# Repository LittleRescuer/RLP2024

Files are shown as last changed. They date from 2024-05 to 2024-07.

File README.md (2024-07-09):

# Little Rescuer
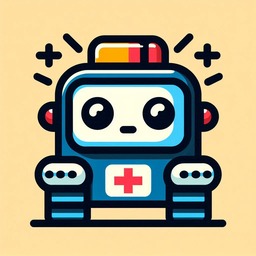
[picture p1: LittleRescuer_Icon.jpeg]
Project Icon


## Descripción

"Little Rescuer" es el prototipo de un robot autónomo diseñado para intervenir rápidamente en situaciones de emergencia en la carretera. Este dispositivo, con forma de automóvil compacto, está equipado con una variedad de funciones para garantizar la seguridad y el bienestar de los conductores y pasajeros involucrados en un accidente.

Cuando se produce un accidente, "Little Rescuer" se tiene que dejar en el suelo para que rápidamente se desplace y se posicione estratégicamente a 200 metros detrás del vehículo afectado.

Una vez en posición, "Little Rescuer" despliega una cámara que puede girar 180 grados, para capturar imágenes de la escena del accidente. Estas imágenes se envían de inmediato  a los contactos de emergencia designados por el conductor, proporcionando una rápida confirmación de que todos están bien. Una vez realizado el aviso, dicha cámara gira y se queda enfocando al tráfico para ir controlándolo.

Además de tomar fotografías, "Little Rescuer" activa su luz rotativa de emergencia V-16 para alertar a otros conductores sobre la presencia del accidente. Esta función ayuda a prevenir colisiones adicionales y garantiza la seguridad en la carretera.

En resumen, "Little Rescuer" es un valioso aliado en situaciones de emergencia en la carretera, ofreciendo una respuesta rápida y coordinada para proteger la seguridad y el bienestar de todos los involucrados en un accidente de tráfico, evitando situaciones de peligro al tener a peatones en la calzada.

## Imágenes
A continuación, mostramos una imagen de como se ve físicamente el robot. No obstante, hay más imágenes en la [siguiente carpeta](./img):
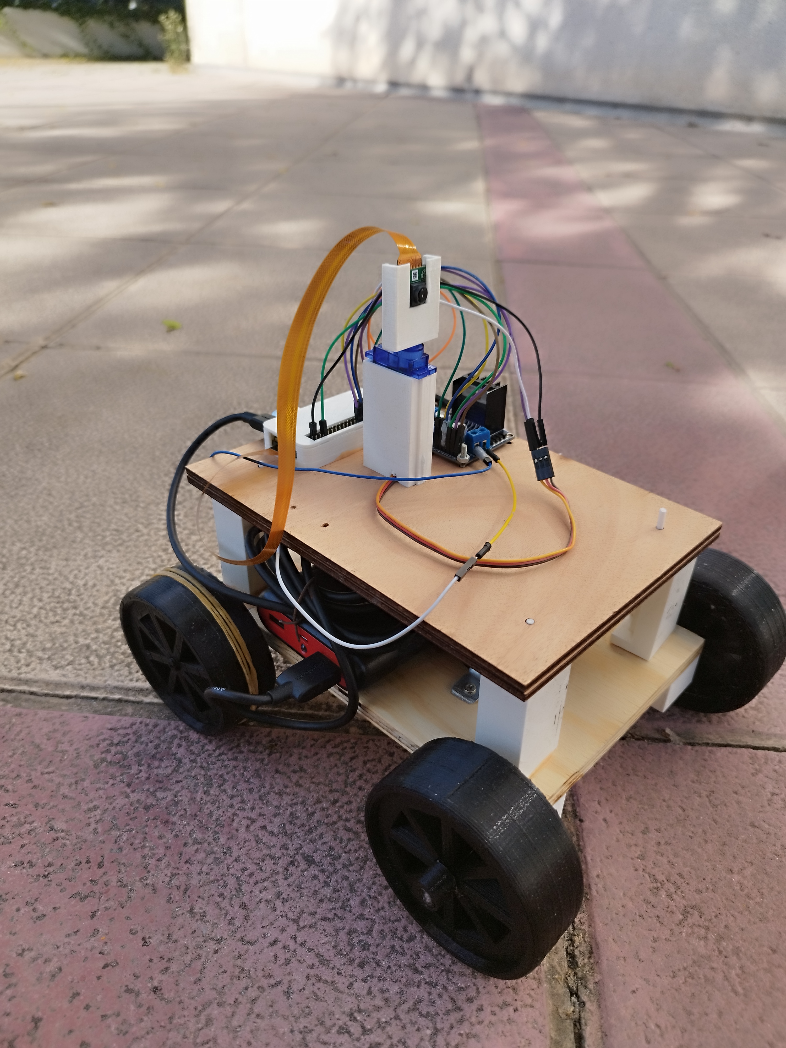
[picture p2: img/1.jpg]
Little Rescuer Image


## Librerías

- Python 3.x
- Raspberry Pi OS Lite
- OpenCV 4.8.0+
- gpiozero
- requests
- picamera2
- numpy
- RPi.GPIO

### Hardware

| Imagen | Descripción | Link |
| --- | --- | --- |
| Cámara Raspberry Pi v2 - 8 Megapixels | Cámara Raspberry Pi v2 - 8 Megapixels | [Link](https://tienda.bricogeek.com/accesorios-raspberry-pi/822-camara-raspberry-pi-v2-8-megapixels.html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) |
| Kit básico Raspberry Pi Zero Wifi + MicroSD 32GB | Kit básico Raspberry Pi Zero Wifi + MicroSD 32GB | [Link](https://tienda.bricogeek.com/placas-raspberry-pi/1082-kit-basico-raspberry-pi-zero-wifi-microsd-32gb.html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) |
| Controlador de motores TB6612FNG | Controlador de motores TB6612FNG | [Link](https://tienda.bricogeek.com/controladores-motores/999-controlador-de-motores-tb6612fng.html?gad_source=1) |
| Motor con eje ángulo recto y reductora 48:1 | Motor con eje ángulo recto y reductora 48:1| [Link](https://tienda.bricogeek.com/motores-dc/1048-motor-con-eje-angulo-recto-y-reductora-481.html) |
| Batería AA recargable - NiMH 2500mAh | Batería AA recargable - NiMH 2500mAh| [Link](https://tienda.bricogeek.com/baterias-lipo/315-bateria-aa-recargable-nimh-2500mah.html) |
| Base para baterías (4xAA) | Base para baterías (4xAA)| [Link](https://tienda.bricogeek.com/componentes/160-base-para-baterias-4xaa.html) |
| Luz emergencia V16 | Luz emergencia V16| [Link](https://www.amazon.es/dp/B0CPB1296V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) |
| Motor servo SG90 | Motor servo SG90| [Link](https://www.amazon.com/-/es/DIYables-grados-Arduino-ESP8266-Raspberry/dp/B0C7BL12RG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) |
| Antena GPS (SIM808) | Antena GPS (SIM808)| [Link](https://www.amazon.com/-/es/SIM808-SIM908-desarrollo-disponible-arduino/dp/B0CJ7VSG82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) |
| Power Bank 10000mAh Dual 2.4A Cargador de Banco de Energía de Alta Velocidad Entrada USB-C Paquete de Bater ía Externa para Teléfono Celular iPhone 12 iPad Samsung S21 Huawei Xiaomi etc | Power Bank 10000mAh Dual 2.4A Cargador de Banco de Energía de Alta Velocidad Entrada USB-C Paquete de Bater ía Externa para Teléfono Celular iPhone 12 iPad Samsung S21 Huawei Xiaomi etc| [Link](https://www.amazon.es/10000mAh-Cargador-Energ%C3%ADa-Velocidad-Tel%C3%A9fono/dp/B09K3BQBW6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) |
| Cable USB C a Micro USB | Cable USB C a Micro USB| [Link](https://www.amazon.com/-/es/flexible-soporta-sincronizaci%C3%B3n-compatible-MacBook/dp/B0BX5G8WNZ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) |

### Schematic
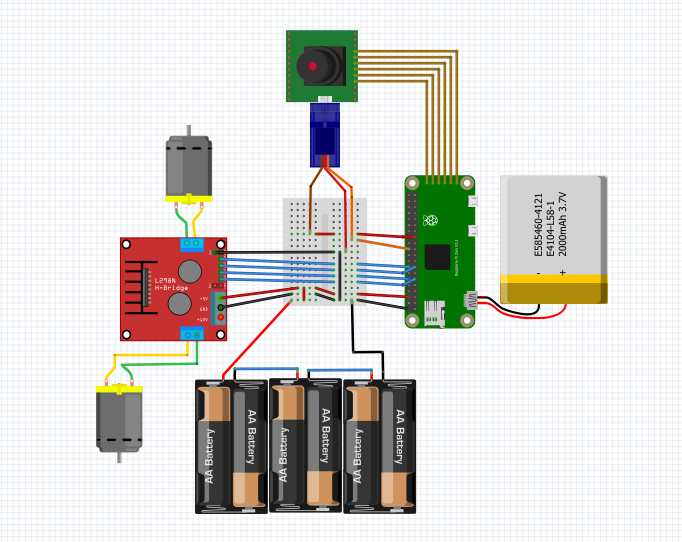
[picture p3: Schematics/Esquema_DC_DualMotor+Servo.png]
Schematic


### 3D

Se pueden encontrar los componentes 3D  [aquí](./Modelo/Componenetes%20Chasis)

### Diagrama de arquitectura del Software
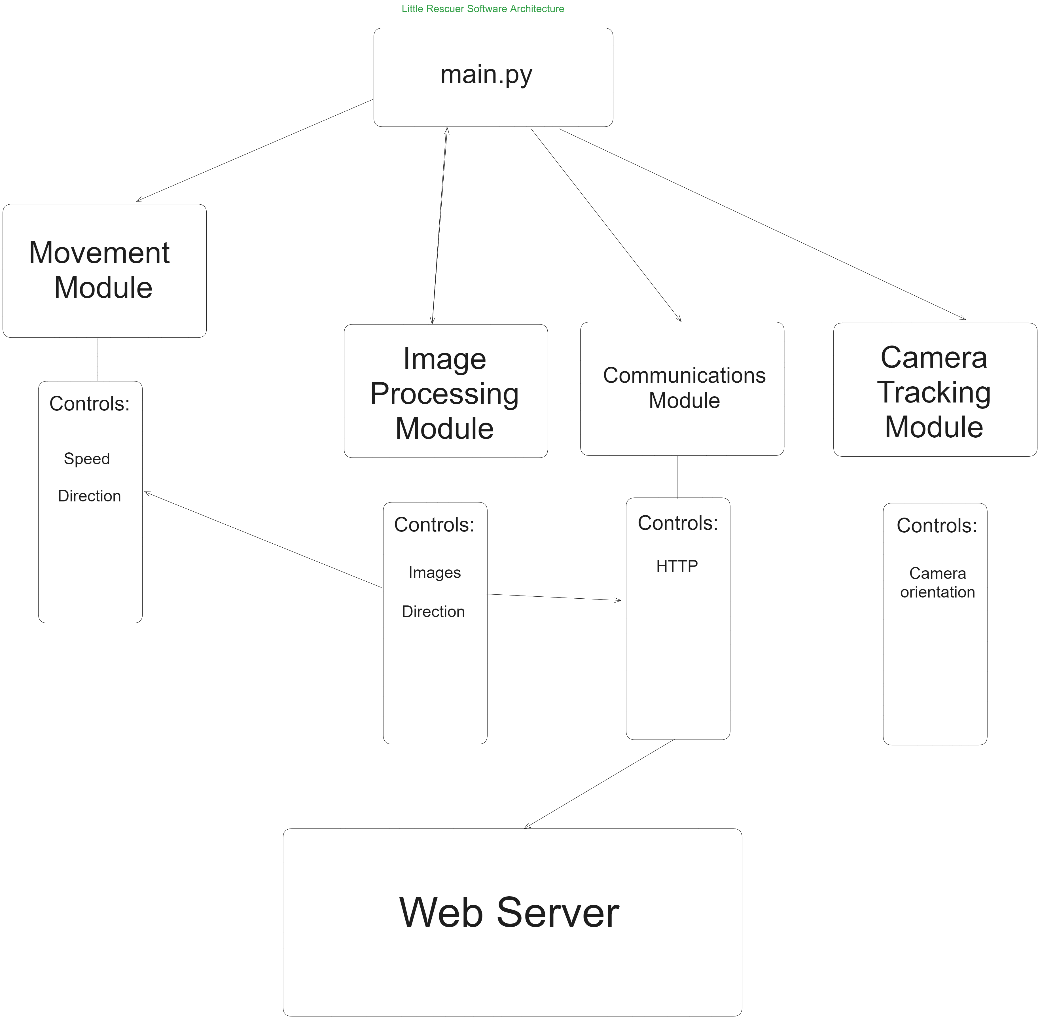
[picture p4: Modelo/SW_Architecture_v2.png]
Diagrama de arquitectura del Software del proyecto LittleRescuer (UAB)


### Página Web

Little Rescuer también cuenta con una página web donde se pueden ver forografías tomadas por el robot. Estas fotografías se realizan una vez el robot ha llegado a la distancia de seguridad de 200 metros alejado del vehículo averiado. Se muestran todas las imágenes que se han realizado con la fecha de realización y un botón de descarga. La página web se puede consultar [aquí](https://little-rescuer.vercel.app).

### Refs
Los proyectos que hemos usado como referencia son:
- [Autonomous Autonavigation Robot (Arduino)](https://www.instructables.com/Autonomous-Autonavigation-Robot-Arduino/)
- [Self Driving Car Using Arduino(autonomous Guided Vechicle)](https://www.instructables.com/Self-Driving-Car-Using-Arduinoautonomous-Guided-Ve/)
- [PythonRobotics](https://github.com/AtsushiSakai/PythonRobotics)
- [DeepPiCar](https://github.com/dctian/DeepPiCar)

### Autores
- Marc Giró Palacios
- Angel Antonio Gomez Nicolas
- Adrian Stoiciu
- Miguel Vallina Samaniego

### Agradecimientos

Queremos agradecer a nuestros 3 profesores de la asignatura:

- Fernando Luis Vilariño Freire
- Carlos García Calvo
- Vernon Stanley Albayeros Duarte

Gracias a su apoyo, este proyecto ha podido superar todos sus altibajos y llegar a buen término con éxito. Estamos agradecidos por el apoyo y la orientación brindada por nuestros profesores a lo largo de este proyecto. Durante los momentos críticos, ofrecieron su experiencia y conocimientos, permitiéndonos encontrar soluciones efectivas.

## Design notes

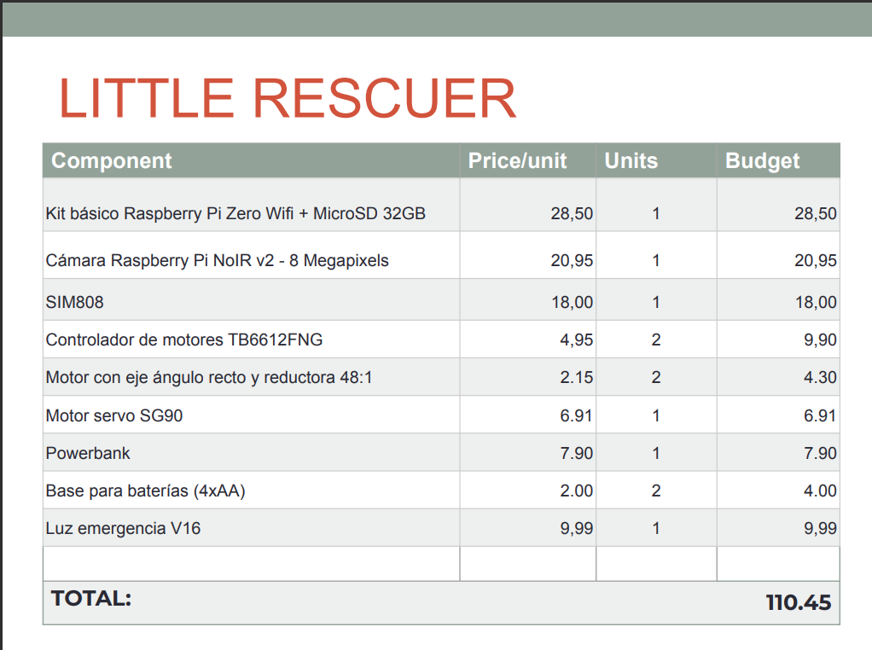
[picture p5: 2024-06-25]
Hardware/Screenshot 2024-06-25 114614.png

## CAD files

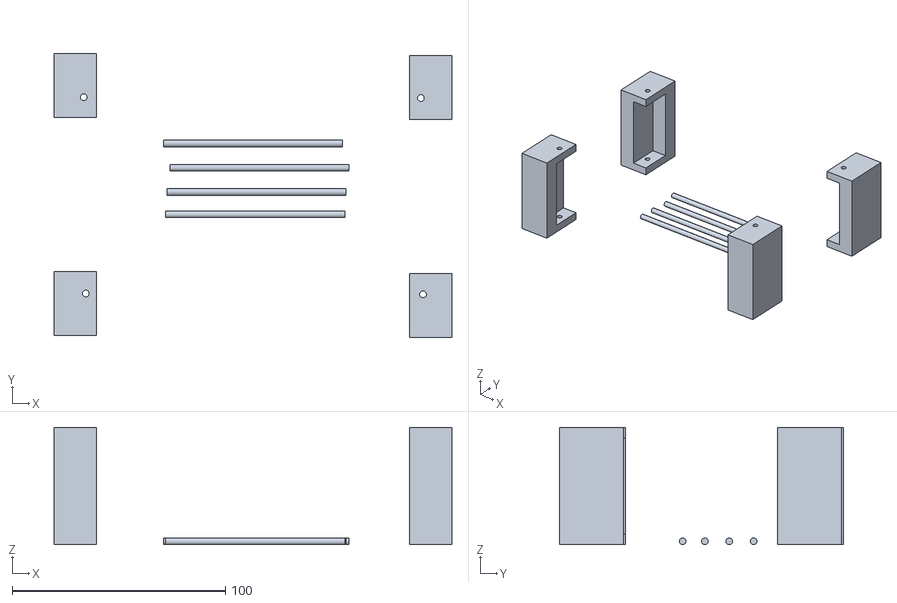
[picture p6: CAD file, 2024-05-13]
Modelo/Componenetes Chasis/LittleRescuer_Middle_Support.stl
186.5 x 133.0 x 55.0

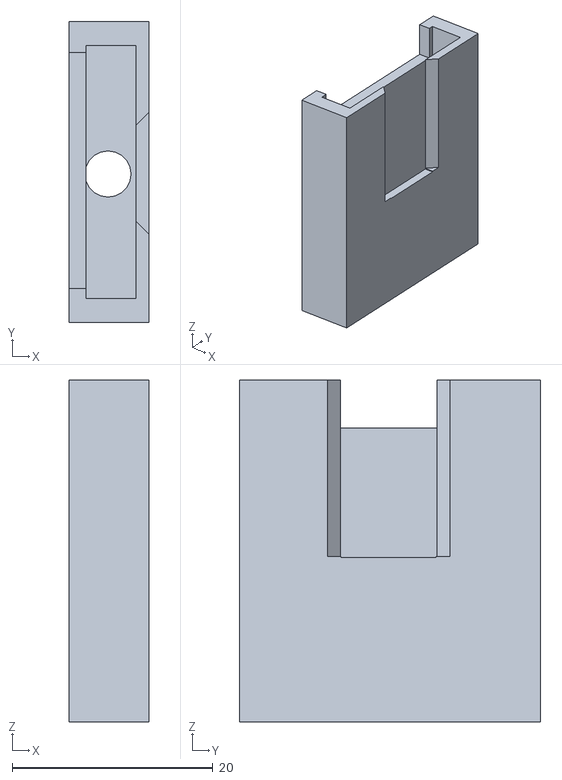
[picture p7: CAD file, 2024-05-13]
Modelo/Componenetes Chasis/LittleRescuer_Cam_Support.stl
8.00 x 30.0 x 34.1

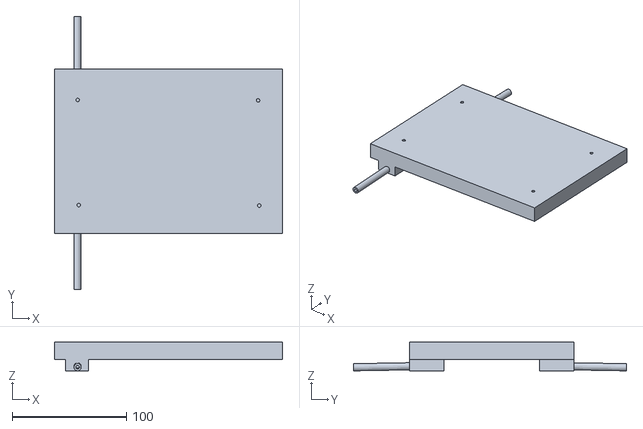
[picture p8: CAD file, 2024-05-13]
Modelo/Componenetes Chasis/LittleRescuer_Lower_Support.stl
200.0 x 239.0 x 25.2

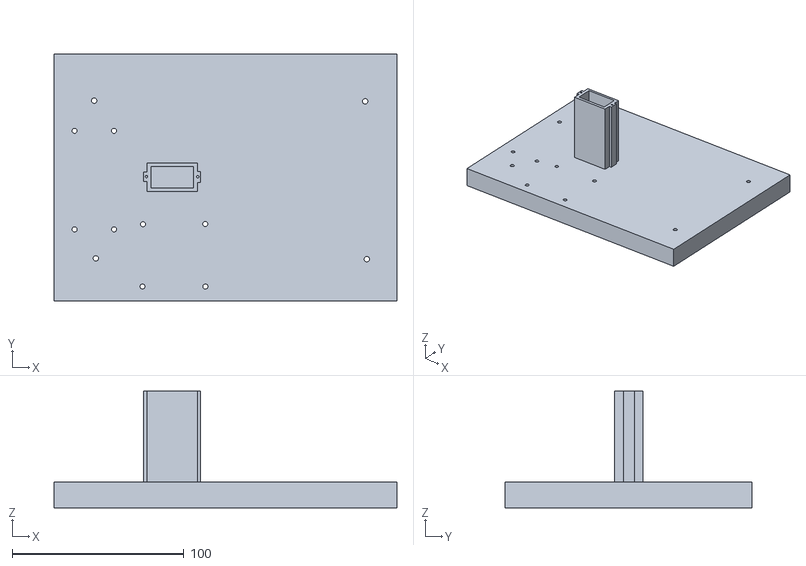
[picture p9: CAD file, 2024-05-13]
Modelo/Componenetes Chasis/LittleRescuer_Upper_Support.stl
200.0 x 144.0 x 68.0

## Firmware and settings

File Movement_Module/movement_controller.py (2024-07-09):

# Necessary Imports
import RPi.GPIO as GPIO
from time import sleep

# All pins in Raspberry Pi Zero
# Power
PWMA = 7 # Power to Right Wheel
PWMB = 18 

# Standby
STBY = 13

# Signal
AIN1 = 12 # Right Wheel to move forward (raspberry pi in front)
AIN2 = 11 # Right Wheel to move backwards (raspberry pi in back)
BIN1 = 15 # Left Wheel to move forward (raspberry pi in front)
BIN2 = 16 # Left Wheel to move backwards (raspberry pi in back)


class MovementController:
    def __init__(self):
        self.pwm_a = PWMA
        self.pwm_b = PWMB
        self.ain1 = AIN1
        self.ain2 = AIN2
        self.stby = STBY
        self.bin1 = BIN1
        self.bin2 = BIN2

        GPIO.setmode(GPIO.BOARD)

        GPIO.setup(PWMA, GPIO.OUT)
        GPIO.setup(PWMB, GPIO.OUT)

        GPIO.setup(AIN1, GPIO.OUT)
        GPIO.setup(AIN2, GPIO.OUT)

        GPIO.setup(STBY, GPIO.OUT)

        GPIO.setup(BIN1, GPIO.OUT)
        GPIO.setup(BIN2, GPIO.OUT)

        GPIO.output(self.pwm_a, GPIO.HIGH)
        GPIO.output(self.pwm_b, GPIO.HIGH)
        GPIO.output(self.stby, GPIO.HIGH)
        print("Movement Controller Initialized")

    def moveForward(self):
        print("Moving Forward")

        # Right Wheel
        GPIO.output(self.ain2, GPIO.HIGH)
        # Left Wheel
        GPIO.output(self.bin2, GPIO.HIGH)
    
    def moveBackward(self):
        print("Moving Backward")
        self.stop()

        # Right Wheel
        GPIO.output(self.ain1, GPIO.HIGH)
        # Left Wheel
        GPIO.output(self.bin1, GPIO.HIGH)

        

    def moveRight(self):
        print("Moving Right")
        self.stop()

        GPIO.output(self.bin2, GPIO.HIGH)

    def moveLeft(self):
        print("Moving Left")
        self.stop()

        GPIO.output(self.ain2, GPIO.HIGH)

    def stop(self):
        print("Stopping")
        GPIO.output(self.ain1, GPIO.LOW)
        GPIO.output(self.ain2, GPIO.LOW)

        GPIO.output(self.bin1, GPIO.LOW)
        GPIO.output(self.bin2, GPIO.LOW)
        GPIO.output(self.stby, GPIO.LOW)
        GPIO.output(self.pwm_a, GPIO.LOW)
        GPIO.output(self.pwm_b, GPIO.LOW)

    def __del__(self):
        GPIO.cleanup()
    

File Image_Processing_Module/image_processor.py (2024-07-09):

# Image_Processing_Module/image_processor.py

import cv2
import numpy as np
from picamera2 import Picamera2


class ImageProcessor:
    def __init__(self):
        self.picam2 = Picamera2()
        self.picam2.start()
        self.__images = []
        print("Image Processor Initialized")

    def capture_frame(self):
        frame = self.picam2.capture_array()
        return cv2.rotate(frame, cv2.ROTATE_180)

    def detect_line(self, frame):
        # Create a copy of the frame for drawing
        display_frame = frame.copy()

        # Convert to grayscale
        gray = cv2.cvtColor(frame, cv2.COLOR_BGR2GRAY)

        # Apply threshold
        _, thresh = cv2.threshold(gray, 200, 255, cv2.THRESH_BINARY)

        # Find contours
        contours, _ = cv2.findContours(thresh, cv2.RETR_EXTERNAL, cv2.CHAIN_APPROX_SIMPLE)

        if contours:
            # Find the largest contour
            largest_contour = max(contours, key=cv2.contourArea)

            # Get the moments of the largest contour
            M = cv2.moments(largest_contour)

            if M["m00"] != 0:
                # Calculate the centroid of the contour
                cx = int(M["m10"] / M["m00"])
                cy = int(M["m01"] / M["m00"])

                # Draw the contour and centroid on the display frame
                cv2.drawContours(display_frame, [largest_contour], 0, (0, 255, 0), 2)
                cv2.circle(display_frame, (cx, cy), 7, (0, 0, 255), -1)
                cv2.putText(display_frame, f"({cx}, {cy})", (cx - 20, cy - 20),
                            cv2.FONT_HERSHEY_SIMPLEX, 0.5, (0, 0, 255), 2)

                # Draw a vertical line at the center of the frame
                frame_center = frame.shape[1] // 2
                cv2.line(display_frame, (frame_center, 0), (frame_center, frame.shape[0]), (255, 0, 0), 2)

                return cx, display_frame

        # If no line is detected, just draw the center line
        frame_center = frame.shape[1] // 2
        cv2.line(display_frame, (frame_center, 0), (frame_center, frame.shape[0]), (255, 0, 0), 2)
        self.__images.append(frame)
        return None, display_frame
    
    def writeImage(self, frame, file_name):
        cv2.imwrite(file_name, frame)

    def close(self):
        for frameIndex in range(len(self.__images)):
            self.writeImage(self.__images[frameIndex], f"frame_{frameIndex}.jpg")
        self.picam2.close()

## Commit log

2024-05-13 Añadiendo los componentes enviados a imprimir
    [LittleRescuer_Cam_Support.stl, LittleRescuer_Lower_Support.stl, LittleRescuer_Middle_Support.stl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]
2024-06-25 Skeleton + Schematic
    [Raspberry_DC_DualMotor_Servo_Entrega.fzz]
2024-06-29 Primera version de la web app para ver las fotografias tomadas por LittleRescuer
2024-07-07 Avances importantes en la estructura de los ficheros y su contenido
2024-07-08 servo controlling added
